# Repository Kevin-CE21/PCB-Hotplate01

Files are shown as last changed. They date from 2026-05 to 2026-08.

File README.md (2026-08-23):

# PCB Hotplate Project (KiCad)
## PCB Layout:
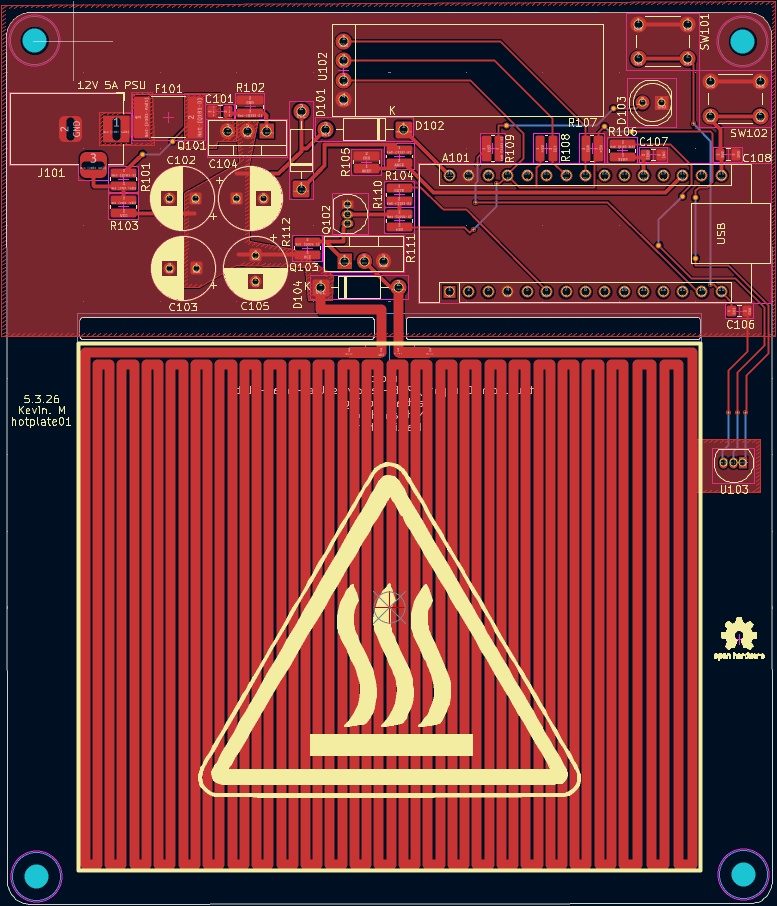
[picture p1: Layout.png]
PCB

## Schematic: 
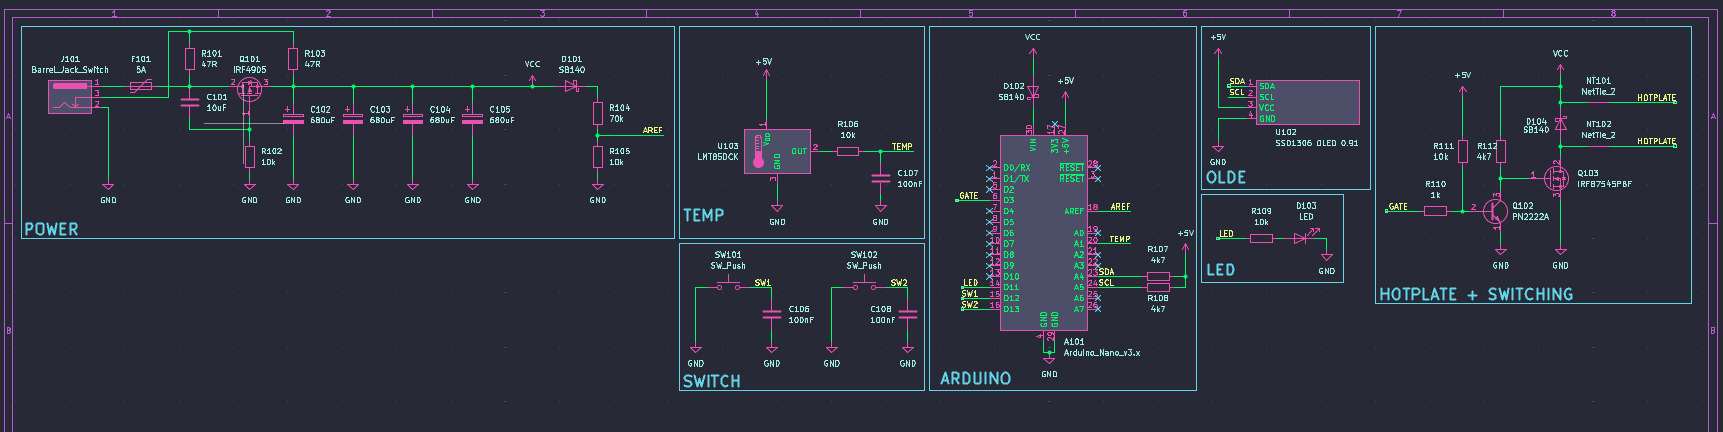
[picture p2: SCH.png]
Schematic

## 3D Model:
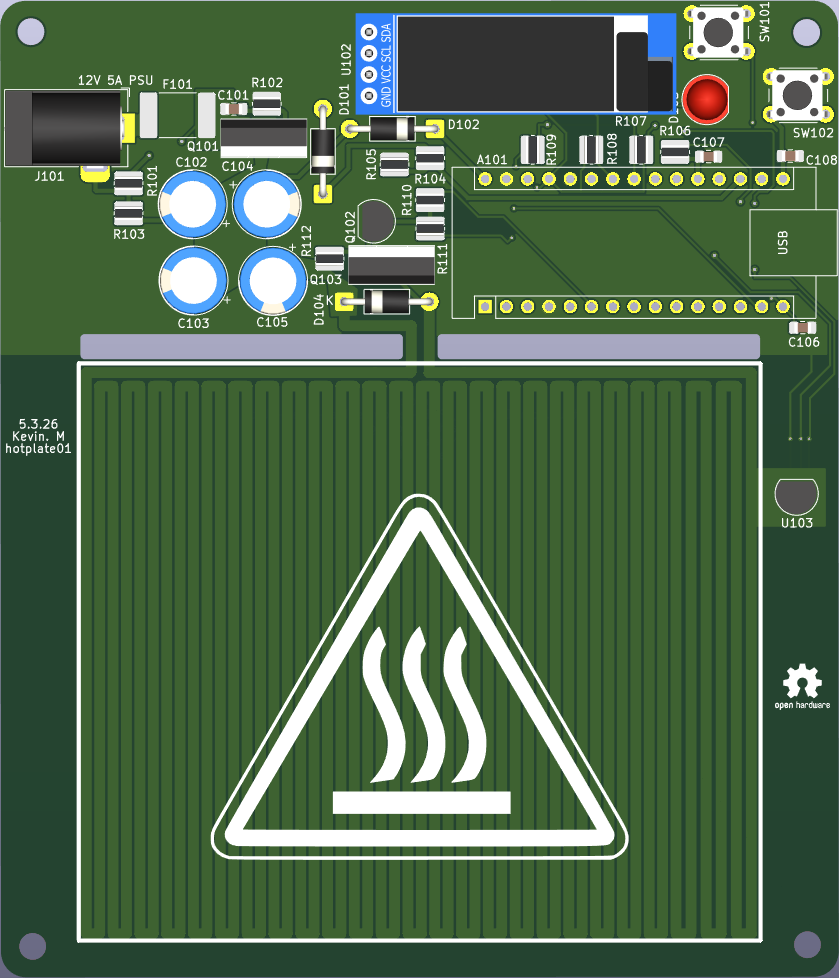
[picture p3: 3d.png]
3D Modle

## Overview

This project is a custom designed PCB hotplate for reflow soldering, built around an Arduino Nano. The board reads real time temperature through an analog LMT85 sensor and displays live readings on an I2C OLED screen, with two push buttons for user control. The heating element is not a discrete part. It is the copper PCB trace itself, laid out in a serpentine pattern across roughly 3.4 meters of 1.3 mm wide, 1 oz copper. At room temperature that trace measures about 1.3 ohms, which would pull over 9 A at 12 V if driven at full duty cycle. Since copper resistance rises with temperature, the trace is self limiting: current settles toward 5 to 6 A as it heats past 200 degrees C. Heating is switched using a low side IRFB7545 power MOSFET, driven through a PN2222A transistor for proper gate level switching, with Schottky diode protection and bulk capacitance across the power rail to maintain stability during high current switching events. Firmware manages duty cycle to stay within the 5 A fuse and supply rating, especially during the cold start ramp.

## Objectives

Design schematic in KiCad

Create custom PCB layout with the heating element integrated directly into copper

Handle higher current safely across a wide range of trace resistance as it heats

Separate power and control sections

Apply proper trace width for the heating load and calculate expected current draw

## Tools Used

KiCad

ERC and DRC checks

PCB layout editor

3D viewer

## System Design

The board includes:

Power input section

Heating element output

Control circuit

Switching device (MOSFET or transistor)

Protection components

Power traces are wider to handle higher current.
Signal traces are separated to reduce noise.

## Design Considerations

Calculated trace width based on expected current

Added thermal relief on pads

Placed high current components close together

Kept control logic isolated from heating path

Used ground plane for stability

## Skills Demonstrated

Schematic capture

PCB layout design

Power electronics basics

Trace width calculation

Design rule verification

Component placement strategy

## What I Learned

Current affects trace width directly

Layout affects heat distribution

Component placement affects performance

ERC and DRC checks prevent costly mistakes

## Possible Improvements

Add temperature sensor feedback

Add PID temperature control

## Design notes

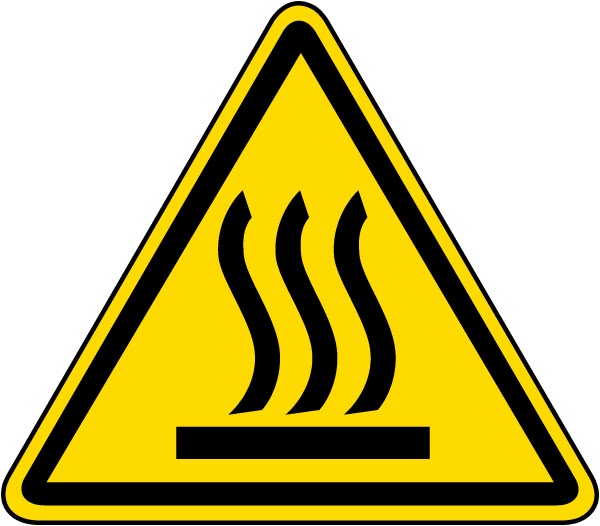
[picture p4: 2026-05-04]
hotolate01/DOC/Hot Surface Warning Label.jpg

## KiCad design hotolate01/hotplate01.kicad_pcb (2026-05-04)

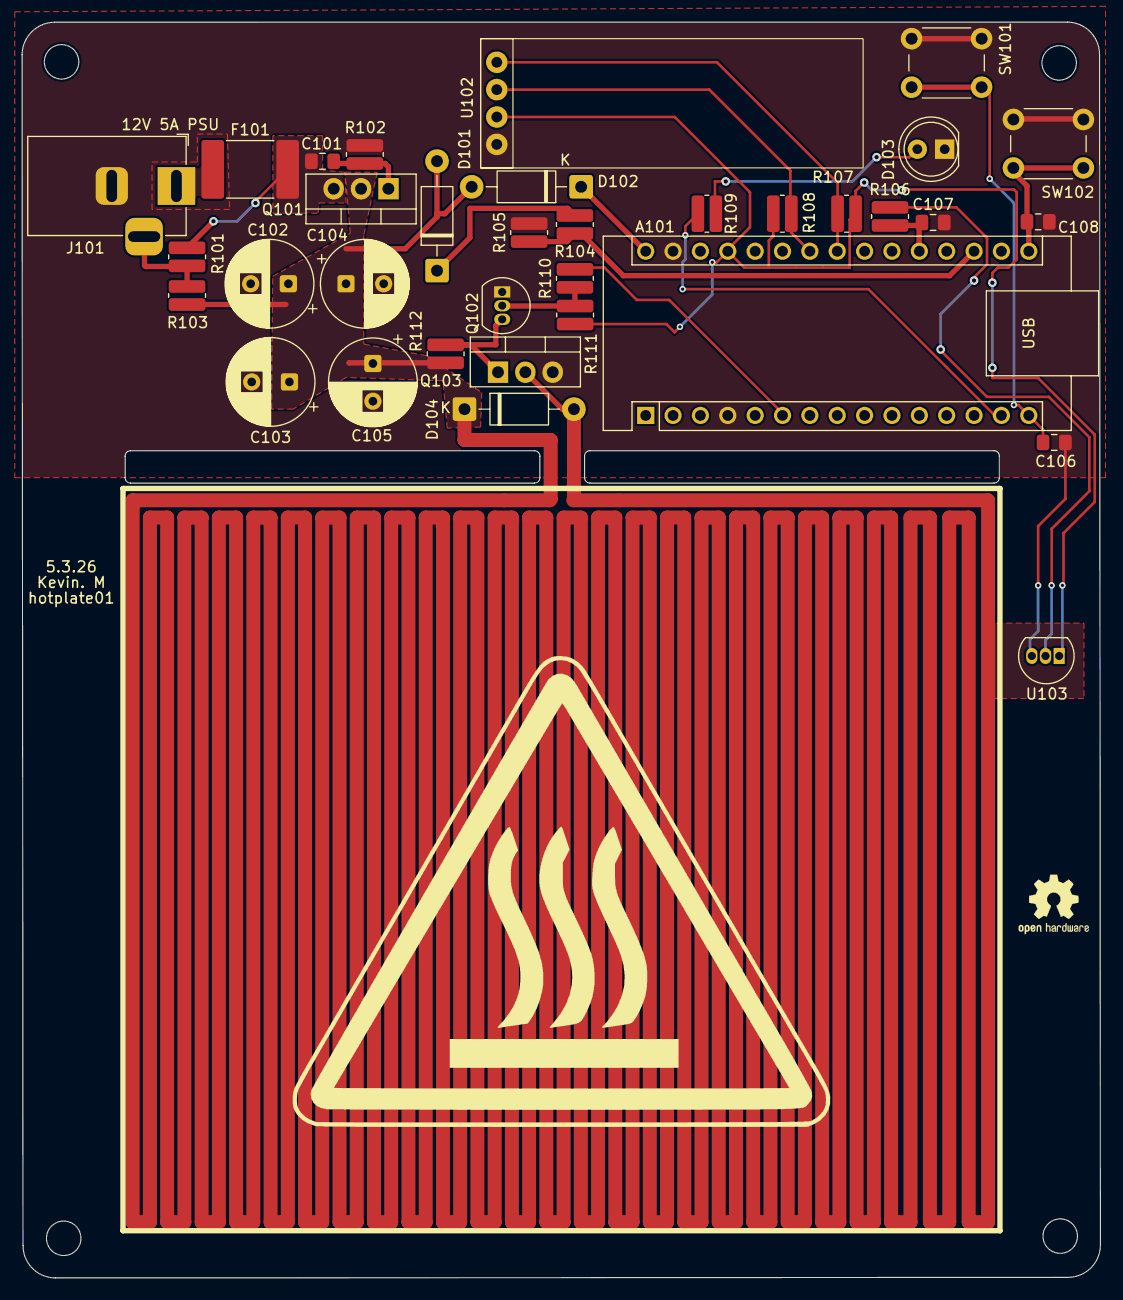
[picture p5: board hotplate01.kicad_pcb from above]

Board: 2 copper layers, 100.1 x 116.6 mm, 36 parts (0 on the bottom side), 23 nets.

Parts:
A101: Arduino_Nano_v3.x; Arduino_Nano
C101: 10uF; C_0805_2012Metric_Pad1.18x1.45mm_HandSolder
C102, C103, C104, C105: 680uF; CP_Radial_D8.0mm_P3.50mm
C106, C107, C108: 100nF; C_0805_2012Metric_Pad1.18x1.45mm_HandSolder
D101, D102, D104: SB140; D_DO-41_SOD81_P10.16mm_Horizontal
D103: LED; LED_D5.0mm
F101: 5A; Fuse_2920_7451Metric_Pad2.10x5.45mm_HandSolder
J101: Barrel_Jack_Switch; BarrelJack_Horizontal
NT101, NT102: NetTie_2; NetTie-2_SMD_Pad1.3mm
Q101: IRF4905; TO-220-3_Vertical
Q102: PN2222A; TO-92_Inline
Q103: IRFB7545PBF; TO-220-3_Vertical
R101, R103: 47R; R_0612_1632Metric_Pad1.18x3.40mm_HandSolder
R102, R105, R106, R109, R111: 10k; R_0612_1632Metric_Pad1.18x3.40mm_HandSolder
R104: 70k; R_0612_1632Metric_Pad1.18x3.40mm_HandSolder
R107, R108, R112: 4k7; R_0612_1632Metric_Pad1.18x3.40mm_HandSolder
R110: 1k; R_0612_1632Metric_Pad1.18x3.40mm_HandSolder
SW101, SW102: SW_Push; SW_PUSH_6mm
U102: SSD1306 OLED 0.91; ssd1306oled0.91
U103: LMT85DCK; TO-92L_Inline

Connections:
+5V: A101.27 (+5V), R107.1, R108.1, R111.1, U102.3 (VCC), U103.1 (V_{DD})
/AREF: A101.18 (AREF), R104.2, R105.1
/GATE: A101.6 (D3), R110.1
/HOTPLATE: NT101.1, NT102.2
/LED: A101.14 (D11), R109.2
/SCL: A101.24 (A5), R108.2, U102.2 (SCL)
/SDA: A101.23 (A4), R107.2, U102.1 (SDA)
/SW1: A101.15 (D12), C106.1, SW101.2
/SW2: A101.16 (D13), C108.1, SW102.2
/TEMP: A101.20 (A1), C107.1, R106.1
GND: A101.4 (GND), A101.29 (GND), C102.2, C103.2, C104.2, C105.2, C106.2, C107.2, C108.2, D103.1 (K), J101.2, Q102.1 (E), Q103.3 (S), R102.2, R105.2, SW101.1, SW102.1, U102.4 (GND), U103.3 (GND)
unnamed: A101.30 (VIN), D102.1 (K)
unnamed: D101.1 (K), R104.1
unnamed: D103.2 (A), R109.1
unnamed: D104.2 (A), NT102.1, Q103.2 (D)
unnamed: F101.1, J101.1
unnamed: J101.3, R101.1, R103.1
unnamed: C101.1, F101.2, Q101.3 (S), R101.2
unnamed: C101.2, Q101.1 (G), R102.1
unnamed: Q102.2 (B), R110.2, R111.2
unnamed: Q102.3 (C), Q103.1 (G), R112.2
unnamed: R106.2, U103.2 (OUT)
VCC: C102.1, C103.1, C104.1, C105.1, D101.2 (A), D102.2 (A), D104.1 (K), NT101.2, Q101.2 (D), R103.2, R112.1

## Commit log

2026-05-04 Update images in README for PCB Hotplate Project
2026-05-04 Update schematic image reference in README.md
